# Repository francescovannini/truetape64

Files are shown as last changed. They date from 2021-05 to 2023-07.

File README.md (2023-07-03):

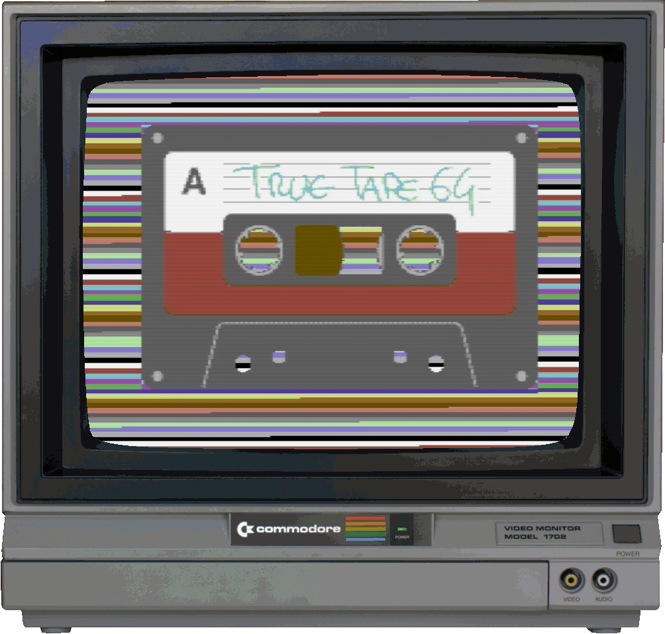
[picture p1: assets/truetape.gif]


# TrueTape64

A cheap, easy to build adapter to interface a [Commodore 1530 (C2N) Datasette ](https://en.wikipedia.org/wiki/Commodore_Datasette) to your PC to dump and preserve your aging Commodore 64 software collection, as accurately as possible.

## What?!

Back in the '80s, many home computers used audio cassette tapes as a medium to to store data. Floppy disks already existed but they often required complex, dedicated hardware; tapes and tape decks on the other hand were cheap, common medium used for music and required simpler or in some cases (like Apple-II) no extra hardware or peripheral. Data was stored encoded as audio and it sounded very similar to the well-known squeaky modem / fax sounds. This storage method had obviously several downsides: long loading/saving times, wasn't "random access" so it required the user to manually advance the tape to the right position to access the desired file; and reliability depended a lot on the quality of the tape. But all these were more than acceptable compromises to keep the prices of these systems down and give everyone a cheap, good-enough way to access or build large software libraries.

As many other future developers born in the '80s, I've started writing BASIC code on a [Commodore 64](https://en.wikipedia.org/wiki/Commodore_64) when I was just a kid. Being still today a huge fan of this platform and having a large collection of tapes, during the past years I've found myself thinking about how to save all this data from the inevitable demise of its aging physical support. 

COVID-19 pandemic gave me some time to finally see if I could figure out how to do that and have some fun while doing it.

### But it has already been done...

Yes, this is certainly not the first project that addresses this issue; in fact I've tried a bunch of existing solutions in the past ([here](http://www.zimmers.net/anonftp/pub/cbm/crossplatform/transfer/datassette/index.html) a comprehensive list) before deciding to design my own device. 

One common approach is based only on clever software: the content of the tape is digitized via a standard audio tape deck (meant for music) connected to the input of a PC sound card. The software then analyzes the audio and extracts the data, performing a variety of corrections and fixes if necessary. This method is quite often the first that many people try, including myself, and usually it is good enough. It requires no weird hardware, however at least in my experience, it requires instead some trial and error; fiddling with volume levels, trying different tape decks and dumping the same tape multiple times to be sure it has been read correctly is the norm. This is because the hardware (tape deck and sound card) is designed for music, not for squeaky, highly-pitched noises. These kind of sounds can be very sensible to things like tape [wow and flutter](https://en.wikipedia.org/wiki/Wow_and_flutter_measurement) and to audio equalization or noise reduction filters; things designed to improve music, not data stored as audio.

Another less common approach involves hooking up the original Datassette to the PC via some sort of adapter. The roughest of these is probably [this one](http://web.archive.org/web/20071130192830/http://www.phs-edv.de/c64s/doc/lpt64.htm) which uses nothing more than a cable and the old-fashioned PC parallel port. This kind of approach requires some skills in building a bit of hardware and it also needs the original Datassette. However, the significant advantage over the software-only approach is that the output dump is closer to what a real Commodore machine would produce or ingest. This is due to the fact that the Datassette is a piece of dedicated hardware, featuring on-board specialized circuitry to clean and digitize the signal so that can be fed directly into the Commodore computer. 

### Design goals

I wanted this project to:

1) Be accurate: given a physical tape, loading it with a real C64 and its Datassette would produce the exact same result than loading the dump of that tape into an emulator when the dump is produced by the same Datassette coupled with this project
2) Be as simple as possible to build and use; bare minimum number of components, designed to be electrically tolerant, safe to use with vintage hardware and requiring minimal tuning; a companion software that does one thing only, but it does it well
3) Be pandemic-proof: all components needed to build the hardware are already in my junk drawer or are easy to obtain from online retailers
3) Be open source: there are similar commercially available devices, not all of them come with schematics or firmware source code. This one does.
4) Be fun and nostalgia fuelled: fiddle with technology designed at the end of the '70s, play with your favourite computer and, in the process, rescue code you wrote when you were 7.

What I've gotten so far:

* a simple hardware device that can be assembled in an hour for less than 10€
* a firmware for the Atmel AVR ATTiny2313 microcontroller which runs the device
* a simple Python command line tool that communicates with the microcontroller and generates a TAP dump of your tape

### Theory of operation

##### Pulse length encoding
The [TAP file format specifications](https://ist.uwaterloo.ca/~schepers/formats/TAP.TXT) gives already some good clues about how the data is stored on the tape and what the emulators such as [VICE](https://vice-emu.sourceforge.io/) expect to find. The Datassette page from [Wikipedia](https://en.wikipedia.org/wiki/Commodore_Datasette#Encoding) is also quite clear:

> To record physical data, the zero-crossing from positive to negative voltage of the analog signal is measured. The resulting time between these positive to negative crossings is then compared to a threshold to determine whether the time since the last crossing is short (0) or long (1).

In practice, the analog signal on the tape is a sine wave which goes from 0 to a minimum negative voltage, then to zero again, then to a maximum positive voltage and finally to zero again; this is fundamentally the entire sine period and it represents a "pulse". The hardware inside the Datassette converts the positive part into a TTL level equivalent to 1 and the negative part to a level equivalent to 0 and sends it over the cable.

This signal is then fed from the Datassette port directly into the C64 [Complex Interface Adapter (CIA)](https://www.c64-wiki.com/wiki/CIA) chip, which would simply run a counter clocked by the system clock to count how many clock cycles the sine period took to complete. In practice, the CIA measures how much time passed between two consecutive falling edges: 
* beginning of the current sine period: negative half-wave on tape, falling edge as seen by the CIA
* end of the current sine period, positive half-wave approaching 0, falling edge as seen by the CIA

If instead of feeding this signal to the CIA we feed it to a microcontroller with a fast enough clock, we could accurately capture the pulse length and then send it somehow to the software running on PC side; tihs is the basic principle behind this project. 

#### Clock speed

But how fast this clock needs to be? The original Commodore LOAD/SAVE routines in the C64 Kernal were designed to be resilient; they used long period pulses producing a relatively low frequency sound which could be safely stored even by low grade tape, but on the other hand loading/saving time were quite long. 

Developers quickly figured out that they could use their own routine to interact directly with the CIA and measure the lenght of each pulse, allowing them to use arbitrary pulse lengths, including very short ones; shorter pulses naturally meant faster loading time. [This article from COMPUTE! magazine](https://www.atarimagazines.com/compute/issue57/turbotape.html) from February 1985 gives an awesome (for a magazine) technical explanation about a popular "tape loader" of the era. Tape loaders were many so many are the different encodings you can find on old tapes. It's therefore obvious that we can't make any assumption on the length of the pulses we could find on the tape; we have to build something that can sample the shortest pulse the CIA can sample. 

We could run the microcontroller at the same clock speed used by the CIA, right? Yes, but how about running it more than TWICE as fast instead? This would ensure we capture data with twice the accuracy as the CIA would do.

##### Sending data over the PC

Once the pulse length is detected we need to send it to our software counterpart running on the PC for it to assemble into the output TAP file. Our microcontroller has a serial port that is fast enough to cope with the bitstream coming from the tape so interfacing that with a ultra common USB adapter is quite convenient. This also provides power to the entire system via the USB port.

##### The Datassette tape motor

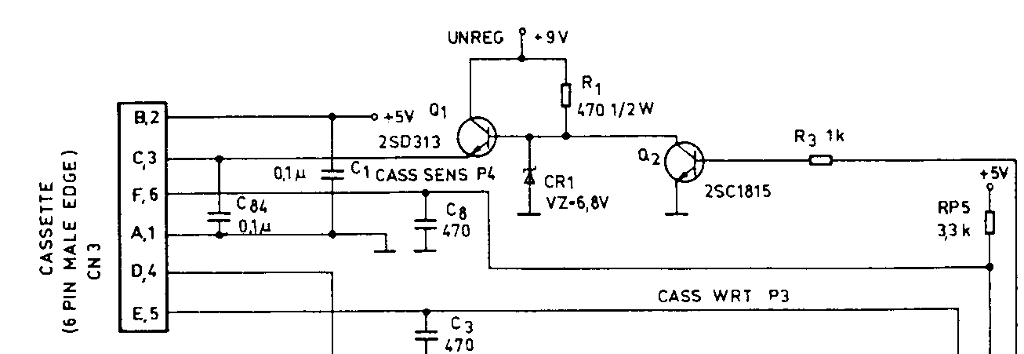
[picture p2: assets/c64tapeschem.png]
c64tapeschem
The Datassette requires two input voltages: a 5V for the TTL logic and a ~6V for the tape motor.  As visible from the original C64 schematics, the C3 pin is fed from the unregulated 9V supplied by the power brick via a transistor and a 6.8V zener diode. This results in a quite stable ~6V output. However the motor voltage isn't critical; each datassette has a slightly different tape speed due to its rudimental mechanics, plus there are different models of Datassette around so the C64 has to be tolerant when measuring pulse length. 

To keep things simple, we opted to include a common DC-DC boost converter to take care of raising the voltage from the USB port from 5V to around 6.1V. Some similar projects use 5V for the motor, running the tape a bit slower and relying on software to compensate for this. I did not try this approach as I was aiming at accuracy but perhaps it would work good enough.

### Schematics and parts

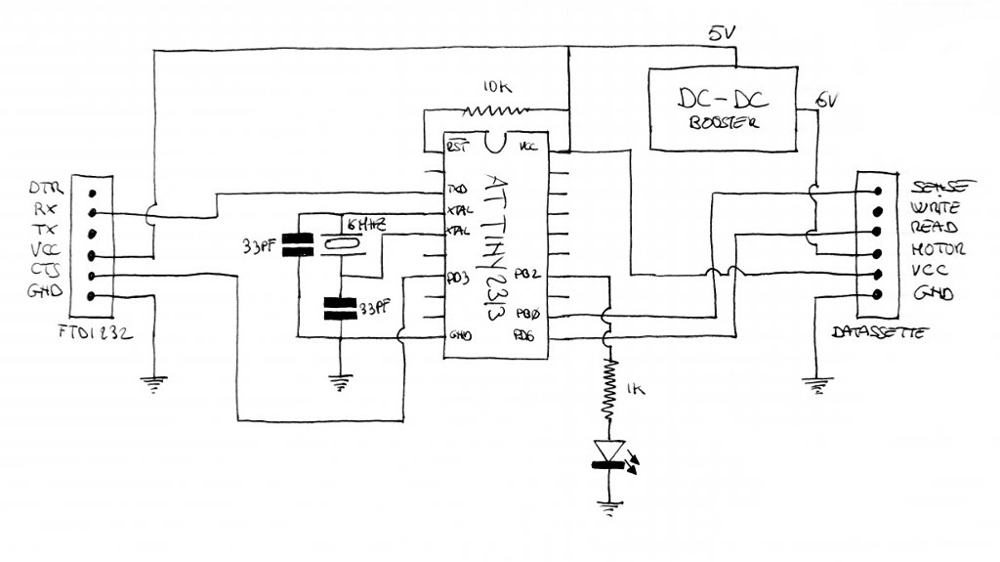
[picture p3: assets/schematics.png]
schematics

Parts:

* [Atmel ATTiny2313-20PU](http://ww1.microchip.com/downloads/en/DeviceDoc/Atmel-2543-AVR-ATtiny2313_Datasheet.pdf)
* 16MHz crystal
* 33pF ceramic capacitors (2x)
* 10KΩ resistor
* 1KΩ resistor
* Red LED
* DC-DC booster module (for example, [this one](https://www.amazon.com/Converter-Voltage-Adjustable-Step-up-Circuit/dp/B07XG323G8/))
* FTDI232 serial to USB adapter (for example, [this one](https://www.amazon.com/HiLetgo-FT232RL-Converter-Adapter-Breakout/dp/B00IJXZQ7C/))
* Datassette edge connector (for example, [this one](https://www.ebay.com/itm/233499875028))
* 5x7 Perf board (for example [this one](https://www.amazon.com/uxcell-Universal-Printed-Circuit-Soldering/dp/B07FK5DWHR))
* 6 pins female header connector

The Datassette READ line is fed directly into PD6/ICP of the uC. This pin is the Input Capture Pin of the 16-bit Timer/Counter1 which can be programmed to generate an interrupt every time a falling edge is detected. The timer runs freely until either an overflow or a falling edge interrupt occurs. In the second case, this allows us to "timestamp" the edge with the value from the counter. 

The clock for the Timer/Counter1 is obtained by dividing by 8 the main clock, which is provided by the 16MHz crystal, giving a 2MHz sample rate. The C64 PAL clock (which is the default in the TAP format) is 985248Hz, so we are more than twice as fast. This should be more than enough to sample tapes for the NTSC model too (which runs at 1.023MHz) although this would probably require a little fix in the Python code. I have no NTSC tapes so I can't test this.

The SENSE line from the Datassette is essentially the output of a microswitch which is closed when one of the buttons on the Datassette is pressed. This is what makes the C64 detect that you "PRESSed PLAY ON TAPE". We capture this event with the micro and forward it to the Python client via the CTS line of the serial port hooked to PD3.

The led is there to signal "buffer overflow" conditions, which should normally never happen. A buffer overflow happens if the data rate from the tape exceeds the data rate of the serial port. We run the serial port at 250Kbps which should be more than enough for most tapes; however, since there is no hardware or software signaling implemented to notify the Python client that an overflow happened, you need to check this led at the end of the dump. If it had turned on, reset the device and try again.

Everything is powered by the USB port, including the DC-DC boost converter for the motor. 

### First (and probably last) prototype

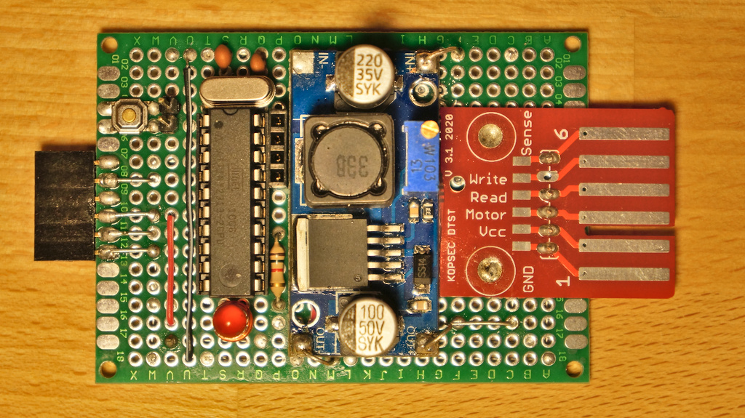
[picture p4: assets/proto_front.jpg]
proto_front

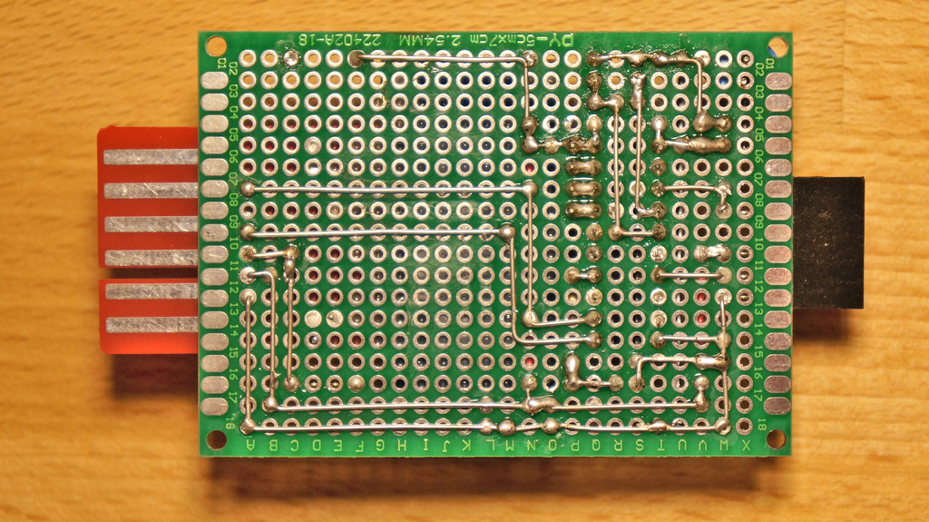
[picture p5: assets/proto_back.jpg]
proto_back

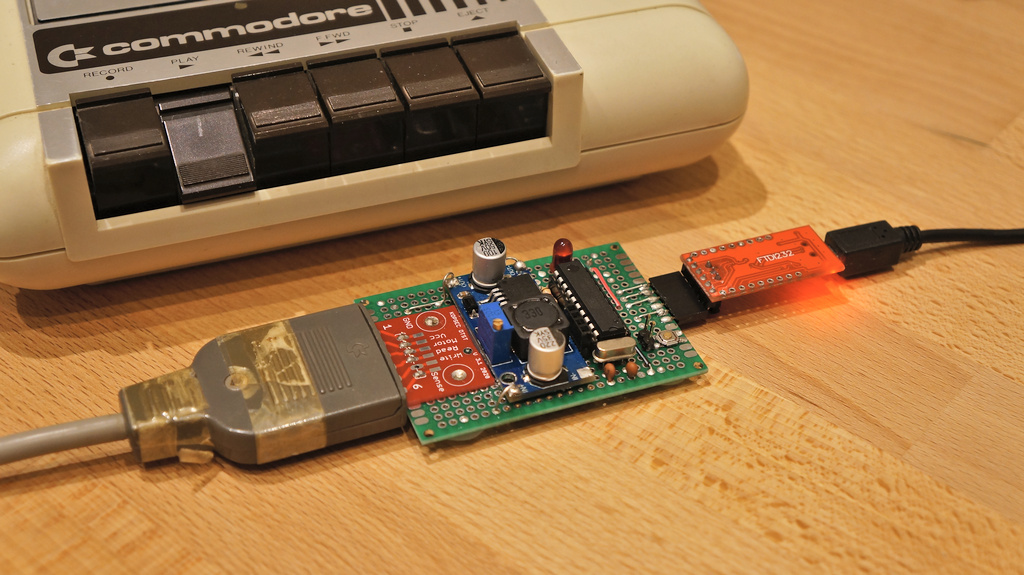
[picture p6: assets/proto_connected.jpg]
proto_connected


Given the simplicity, the whole thing can be built on a perf board or even a breadboard if you don't need a permanent solution. Here the first prototype. The XL6009 booster board is hot-glued on top of the perfboard and connected with rigid wires.

**Adjust the DC-DC boost converter before hooking up a Datassette!** 

Hook up a multimeter between the MOTOR and the GND pins of the Datassette edge connector; using a flat screwdriver, turn the screw on the converter until you read about 6.15V on the multimeter. Now connect the Datassette, put a tape into it and press PLAY. If the voltage drops below 6.1V, adjust the screw again. In any circumstance, be sure the booster never outputs more than 6.5V or you would risk damaging your Datassette motor.

### AVR Firmware

The directory [avr](./avr) in this repo contains the source code of the ATTiny2313 firmware that runs the show on the adapter side. The file `truetape64.hex` is a pre-compiled version of the firmware that you can flash directly onto the AVR using the included Bash script. This script requires avrdude and the usbtiny programmer: check [Lady Ada tutorial](https://learn.adafruit.com/usbtinyisp/avrdude) for further instructions. 

If you flash with your own tool / programmer, remember to also program the fuses:

```
low: 0xFF
high: 0xDF
```

### Python CLI

A simple Python tool is included in the [cli](./cli) directory. The tool opens the serial port of the FTDI adapter and monitors its CTS line; when PLAY is pressed on the Datassette, the tool starts reading the data sent from the microcontroller. After some basic math to account for the differences in frequency between the AVR and the C64 PAL clock, the pulse length is written to the TAP file. The process continues until the CTS line status changes; this can happen either when the tape stops or when there is a buffer overflow; in the latter case, led on the board will be flashing fast until the tape is stopped.

The TAP v2 file format allows for pulse length values for up to 0xFFFFFF (3 bytes). The microcontroller always sends 3 bytes for each pulse, followed by a checksum byte. The checksum is just an extra measure to ensure there is no data corruption during the transfer between the microcontroller and the FTDI adapter, for instance due to a bad solder joint.

See the [README](./cli/) included with the tool for further instructions.

## License
[GPLv3](./LICENSE)

## As seen on Hackaday

This project has been featured on [Hackaday](https://hackaday.com/2021/05/10/truetape64-is-a-pc-interface-for-your-c64-datasette/)

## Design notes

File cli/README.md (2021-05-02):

# TrueTape64 CLI

This tool is part of the TrueTape64 project, aimed at building a simple to build but very reliable interface to dump Commodore 64 tapes into TAP filest suitable to be used with emulators like [Vice](https://vice-emu.sourceforge.io/). Check [here](../) for more infos about the project.

## Installation
    
Be sure to have [pip installed](https://pip.pypa.io/en/stable/installing/), then from the root of this repo, just type
 
    pip3 install .

## Invocation

Simply run the command with no arguments to get help:

    truetape64cli [-d /dev/ttyUSB4] [-y] streetfighter_a.tap
     -d: specify serial device (default is /dev/ttyUSB0) 
     -y: overwrite output file if exists

### Typical output

    $ truetape64cli -d /dev/ttyUSB4 -y streetfighter_a.tap
    PRESS PLAY ON TAPE
    Dumping started
    0 pulses, 0 serial errors, shortest pulse was None
    0 pulses, 0 serial errors, shortest pulse was None
    6 pulses, 0 serial errors, shortest pulse was 26
    13 pulses, 0 serial errors, shortest pulse was 26
    6029 pulses, 0 serial errors, shortest pulse was 20
    16768 pulses, 0 serial errors, shortest pulse was 20

    [...]

    Dumping halted. Dumped 727623 pulses, 0 serial errors, shortest pulse was 2
    Check led status on device

### Practical usage

1) Connect your TrueTape64 adapter to your Commodore Datassette unit
2) Connect your TrueTape64 adapter to one of the USB ports
3) Launch this tool as described above and when prompted...
4) Press PLAY on your Datassette unit
5) Either wait for the tape to reach its end or press STOP when you are done
6) The tool will detect tape activity automatically

If this tool quits before tape reached its end or before you pressed STOP it usually means a hardware error occured during the transfer. This is signaled by a rapidly flashing led on the adapter. In this case press STOP, rewind your tape and start the procedure again. 

The number of serial errors reported by the tool should always be 0. If this number is not zero at the end of the dump, there is a chance that the data has been corrupted or it's missing. If this happens often, replace the FTDI232 adapter with a new one and check the solder joints on your adapter.

## License
[GPLv3](./LICENSE)

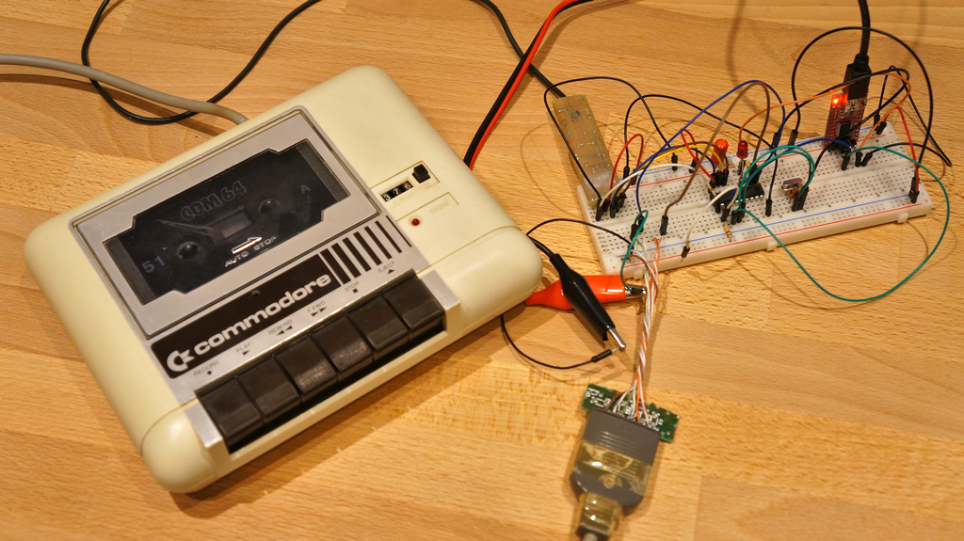
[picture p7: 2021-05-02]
assets/breadboard.jpg

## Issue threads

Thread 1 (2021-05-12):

PCB design

mesmariusz, 2021-05-12:
As I See PCB / gerbers are missing. I'm going to prepare for myself @ KiCad format. If you are interested I could share it for you.

Is this project well tested / works good enough?

francescovannini, 2021-05-12:
I didn't bother producing a proper PCB as this was mostly a small experiment / challenge meant to work just for a few days, to recover all the tapes I have. I tested it with tens of tapes; those which were unreliable after the dump, were unreliable also before, using a real C64; but I could recover data from the dump, so I was definitely happy with the results.
I would certainly be interested in the PCB and schematics if you feel like sharing! Thanks!

mesmariusz, 2021-05-12:
It's great to hear your interface works so much :-) For me this is very nice message, especially because I tried (maybe 25 years ago) the similar solution for LPT port ( https://om.vlip.lv/video/ifxAbwKeGi5f9zE%3D.html ) and it forked for me then (25 years ago). About 3 years ago I try to do it again (many Datasettes, many retro PC's, and many tapeio.exe revisions) but with no result. I dont know why. Everytime load error and notheing more...

https://www.youtube.com/watch?v=Qw3gm-NW9i0&t=20s&ab_channel=MariuszCiszewski
https://www.youtube.com/watch?v=H0MvUC3SV2U&t=80s&ab_channel=MariuszCiszewski
https://www.youtube.com/watch?v=LFOsX8vCoRA&t=4s&ab_channel=MariuszCiszewski

So if your interface works so nice, and with modern PC's (no LPT needed) then for sure and with a great pleasure I will create the circuit drawing and PCB.

Nowadays this is really great if every new hardware is "Arduino compatibile" or build based on Adruino. Even I started to like it ;-). It's easier to program (no programmer is needed, no complicated programm environment, just plug the USB cable, run the Aduino IDE, open .ino file, program and that's all :-) I rally started to like it (previously bare microcontrollers and firmware coded @ Bascom AVR ;-) )

My question: could it be possible for you to prepare the hardware version based on e.g. Arduino Nano (or similar)?
Then I could prepare the hardware ready just to put Arduino module in it, program, and that's all.

If there is any issue to prepare the source @ Arduino language, then of course I can also prepare the documentation (sch, pcb) also for bare microcontroller.

Generally this is really great job, my congratulations :-)

Best regards
Mariusz

francescovannini, 2021-05-13:
Hi Mariusz,

thanks for the feedback! In fact, if you were thinking about an Arduino-based solution, I believe there is already something like this one https://github.com/sweetlilmre/tapuino

mesmariusz, 2021-05-13:
This is possible to connect real Datasette to a PC using Tapuino? Probably not ;-) Tapuino is an emulator / replacement to a real hardware. And I'm searching the nice working solution to connect a real Datasette to a PC. That's quite different topics ;-)

francescovannini, 2021-05-13:
I know, tapuino is kind of the reverse of truetape64, but looking at this board https://github.com/sweetlilmre/tapuino/wiki I see an edge connector; I'm not sure you can directly hook a Datasette there (maybe the motor 6+ voltage isn't provided yet), however I would say that the Tapuino is probably a better starting point for you than my project, since it's already based on Arduino and it more or less has already the hardware that you need...

mesmariusz, 2021-05-13:
Ok, I catch your point right now ;-) I will check the hardware, but the hardware is not an issue in a fact.
The most important is to have checked and well tested Arduino code to implement.
I see your code is also C, so maybe it shouldn't be hard to translate to .ino, but for sure I will find no enough time for that. PCB design is my common daily work right now ;-) It's a several minutes for me. So maybe to make it easier I will prepare the PCB just for bare ATTiny2313 and for Arduino maybe some other day ;-)

francescovannini, 2021-05-13:
Sure, that would be great! For the code, I think it would not make much sense to port it to Arduino as it's extremely simple as it is already and in general bare C performs a little bit better. If you are into circuit design, maybe you can double check if everything is ok, I've surely missed something, I know at least a couple of decoupling capacitors as someone also noticed on Hackaday...

mesmariusz, 2021-05-13:
Generally It make a sense, because e.g. Arduino Nano have build in USB to UART converter, is small and maybe even cheaper (aliexpress) than even single ATTiny microcontroller + FTDI converter + breadboard or universal board. And it's easier and faster to build (just put the arduino to almost bare PCB including edge connector to a Datasette), connect USB cable, upload .ino to Arduino ant thst's all. Easy PCB @ 2 USD per 5 pcs of PCB @ jlpcb, probably it's cheaper and more simple way, even more simple than build it on an universal PCB from a few discrette components ;-)

francescovannini, 2021-05-13:
Precisely! For the hardware what you said it's what Tapuino did ;)

mesmariusz, 2021-05-13:
Tapuino (PCB including edge connector for Datasette variant) is qite big:
https://github.com/sweetlilmre/tapuino/wiki/Tapuino-1.7.jpg

I could make your hardware design:
https://github.com/francescovannini/truetape64/blob/master/assets/proto_connected.jpg?raw=true

much smaller, even smaller than Tapuino ;-)

DC-DC under or above Arduino Nano (similar size), and  just outstanging edge connector for Datasette.
So the final size probably Arduino size and outstanding edge connector :-)

boelle, 2023-09-25:
i just made something in kicad

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

i'm not a programmer, but what would it take to change  the python code so we could also write to tape?

Closed 2022-01-09.

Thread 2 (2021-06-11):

Support record mode

heneault, 2021-06-11:
Thank you for this project. I didn't start it but it is on my todo list!

I would like to know if you consider supporting the record mode ? That would increase the old nostalgic effect by having the ability to push a .tap file from the pc to a real tape being recorded by the 1530. Then, the c64 would be able to read back the tape without compatibility issue since it would have been written by the datassette itself.

francescovannini, 2021-06-25:
Hi! The original purpose of this project was to just dump tapes, not to produce new ones. However, I think with minimal hardware modifications (probably just a couple of extra wires) and a new firmware it would be definitely possible, so why not...

Closed 2022-01-09.

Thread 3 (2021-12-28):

Error sense PIN

Nanths, 2021-12-28:
Hi!

Thank you and congratulations for this project. It seems that the PIN sense was updated in the python code but it wasn't in readme and schematic file. Can you check it? It has to be PD3 but in schematic and readme says PD2. I spent some hours trying to find why it didn't work and what I did wrong, hehe.

Btw, it works great :)

francescovannini, 2022-01-09:
Hey Nanths thanks for spotting this, I've fixed it.
I had changed the ping last minute in the code but forgot to update the docs, sorry for the time you lost on this.
I hope at least it helped dumping some tapes! :)

Closed 2022-01-09.

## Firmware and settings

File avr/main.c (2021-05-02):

#pragma ide diagnostic ignored "hicpp-signed-bitwise"
#pragma ide diagnostic ignored "EndlessLoop"

#include <avr/io.h>
#include <inttypes.h>
#include <avr/interrupt.h>
#include <stdbool.h>
#include <util/delay.h>
#include "main.h"

volatile uint8_t tm_overflows;
volatile pulselen_t pulse_buf[BUF_SIZE];
volatile int8_t pulse_buf_h = -1, pulse_buf_t = -1;
volatile bool pulse_buf_ovf = false;
volatile bool cassette_sense = false;

inline void enqueue_pulse(const volatile uint8_t *tm_overflow, const volatile uint16_t *tm_counter) {

    if ((!cassette_sense) || pulse_buf_ovf) {
        return;
    }

    // Skip too short pulses
    if ((*tm_overflow == 0) && (*tm_counter < MIN_PULSE_LEN)) {
        return;
    }

    if (pulse_buf_h == BUF_SIZE - 1) {
        pulse_buf_ovf = true;
        return;
    }

    if (pulse_buf_h == -1) {
        pulse_buf_h = 0;
    }

    pulse_buf_t++;
    pulse_buf[pulse_buf_t].tm_counter = *tm_counter;
    pulse_buf[pulse_buf_t].tm_overflows = *tm_overflow;
}

inline void send_pulse_data(const volatile pulselen_t *p) {
    uint8_t checksum = 64;

    for (uint8_t i = 0; i < (uint8_t) sizeof(pulselen_t); i++) {
        uint8_t *t = ((uint8_t *) p) + i;
        while (!(UCSRA & (1 << UDRE))) {}
        UDR = *t;
        checksum += *t;
    }

    while (!(UCSRA & (1 << UDRE))) {}
    UDR = checksum;
}

int main(void) {
    bool tmp_sense;

    // Status led
    LED_PORT_DDR |= 1 << LED_PIN;

    // Cassette sense input, Datassette F-6 pin to PB1
    SENSE_IN_PORT_DDR &= ~(1 << SENSE_IN_PIN);
    SENSE_IN_PORT |= 1 << SENSE_IN_PIN; // Pull-up

    // Cassette sense output to serial CTS
    SENSE_OUT_PORT_DDR |= 1 << SENSE_OUT_PIN;
    SET_CASSETTE_SENSE;

    // Capturing falling edges with Timer/Counter 1
    DDRD &= ~(1 << PD6); // Input on PD6
    TIMSK |= (1 << ICIE1) | (1 << TOIE1);     //Set capture interrupt and overflow interrupt
    TCCR1B = (0 << ICNC1) | (0 << ICES1)
             | (0 << CS12) | (1 << CS11) | (0 << CS10);  //Set capture falling edge, /8 prescaler

    // USART init
    UBRRL = UART_UBRR;
    UBRRH = UART_UBRR >> 8;
    UCSRB = (1 << RXEN) | (1 << TXEN) | (0 << U2X); // Enable RX and TX, disable 2X mode
    UCSRC = (0 << USBS) | (1 << UCSZ1) | (1 << UCSZ0); // 8, N, 1

    // Blink when boot done
    LED_PORT |= 1 << LED_PIN;
    _delay_ms(500);
    LED_PORT &= ~(1 << LED_PIN);

    sei();
    for (;;) {

        tmp_sense = !(SENSE_IN_PINS & (1 << SENSE_IN_PIN) >> SENSE_IN_PIN); //FIXME Debounce maybe?
        if (tmp_sense != cassette_sense) {
            cassette_sense = tmp_sense;
            if (cassette_sense) {
                CLR_CASSETTE_SENSE;
            } else {
                SET_CASSETTE_SENSE;
                pulse_buf_ovf = false;
            }
        }

        // Send data in buffer
        if (pulse_buf_h >= 0) {
            send_pulse_data(&pulse_buf[pulse_buf_h]);
            pulse_buf_h++;
            if (pulse_buf_h > pulse_buf_t) {
                pulse_buf_h = -1;
                pulse_buf_t = -1;
            }
        }

        if (pulse_buf_ovf) {
            SET_CASSETTE_SENSE;
            for (uint8_t blink = 0; blink < 5; blink++) {
                LED_PORT |= 1 << LED_PIN;
                _delay_ms(100);
                LED_PORT &= ~(1 << LED_PIN);
                _delay_ms(100);
            }
        } else {
            LED_PORT &= ~(1 << LED_PIN);
        }
    }
}

ISR(TIMER1_CAPT_vect) {
    uint16_t tmp = ICR1;
    TCNT1 = 0;
    enqueue_pulse(&tm_overflows, &tmp);
    tm_overflows = 0;
}

ISR(TIMER1_OVF_vect) {
    const uint16_t max = 0xFFFF;
    if (tm_overflows < 0xFF) {
        tm_overflows++;
    } else {
        enqueue_pulse(&tm_overflows, &max);
        tm_overflows = 0;
    }
}

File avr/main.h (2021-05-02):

#ifndef TRUETAPE64_MAIN_H
#define TRUETAPE64_MAIN_H

#include <inttypes.h>

#define BUF_SIZE            24
#define MIN_PULSE_LEN       9       // Less than this, pulse would appear as 0 in the TAP

#define UART_UBRR           3       // 250kbps at 16Mhz

#define LED_PIN             PB2
#define LED_PORT            PORTB
#define LED_PORT_DDR        DDRB

#define SENSE_IN_PIN        PB0
#define SENSE_IN_PINS       PINB
#define SENSE_IN_PORT       PORTB
#define SENSE_IN_PORT_DDR   DDRB

#define SENSE_OUT_PIN       PD3
#define SENSE_OUT_PORT      PORTD
#define SENSE_OUT_PORT_DDR  DDRD

typedef struct {
    uint16_t tm_counter;
    uint8_t tm_overflows;
} pulselen_t;

#define CLR_CASSETTE_SENSE  SENSE_OUT_PORT &= ~(1 << SENSE_OUT_PIN)
#define SET_CASSETTE_SENSE  SENSE_OUT_PORT |= 1 << SENSE_OUT_PIN

#endif //TRUETAPE64_MAIN_H

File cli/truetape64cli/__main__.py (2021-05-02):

import sys
import getopt
import time
import serial
import os.path
import logging

log = logging.getLogger(__name__)
logging.basicConfig(format='%(message)s', level=logging.INFO)


def verify_checksum(buf):
    checksum = 64
    for bi in range(len(buf) - 1):
        checksum = checksum + buf[bi]

    checksum = checksum % 256

    if buf[3] != checksum:
        return False

    return True


def dump(serial_device, output_file):
    try:
        ser = serial.Serial(serial_device, baudrate=250000, timeout=0)
    except (FileNotFoundError, BrokenPipeError, serial.serialutil.SerialException):
        log.error(f"Cannot open {serial_device}. Be sure it exists and it's connected to the FTDI serial adapter")
        sys.exit(1)

    try:
        tapfile = open(output_file, "w+b")
    except (FileNotFoundError, PermissionError):
        log.error(f"Cannot write to {output_file}.")
        sys.exit(1)

    tap_header = b'\x43\x36\x34\x2D\x54\x41\x50\x45\x2D\x52\x41\x57\x01\x00\x00\x00\x00\x00\x00\x00'
    tapfile.write(tap_header)

    logging.info("PRESS PLAY ON TAPE")
    try:
        while not ser.getCTS():
            time.sleep(0.01)
            continue
    except OSError:
        logging.error("Unrecoverable error while reading from serial device. Aborting")
        sys.exit(1)

    logging.info("Dumping started")

    data_len = 0
    pulses = 0
    shortest_pulse = None
    buffer = bytearray()
    checksum_errors = 0
    last_msg_ts = 0
    dumping = True

    while dumping:

        if time.time() - last_msg_ts > 5:
            last_msg_ts = time.time()
            if pulses > 0:
                logging.info(f"{pulses} pulses, {checksum_errors} serial errors, shortest pulse was {shortest_pulse}")
            else:
                logging.info(f"No pulses detected yet, {checksum_errors} serial errors")

        try:
            b = ser.read()
        except OSError:
            logging.error("Unrecoverable error while reading from serial device. Aborting")
            sys.exit(1)

        if len(b) == 0:
            if not ser.getCTS():
                dumping = False
                continue
            time.sleep(0.1)
            continue

        buffer.append(b[0])
        if len(buffer) == 4:
            if verify_checksum(buffer):
                counter_cycles = buffer[0] + buffer[1] * 0xFF + buffer[2] * 0xFFFF  # 2MHz clock of TC1 via /8 prescaler
                counter_cycles_64 = counter_cycles / 2000000 * 985248  # .98MHz C64 clock conversion
                buffer.clear()
                pulses += 1

                tap_pulse = int(round(counter_cycles_64 / 8 * .985248))

                if shortest_pulse:
                    shortest_pulse = min(shortest_pulse, tap_pulse)
                else:
                    shortest_pulse = tap_pulse

                try:
                    if tap_pulse <= 255:
                        data_len += tapfile.write(tap_pulse.to_bytes(1, byteorder="little", signed=False))
                    else:
                        data_len += tapfile.write(b'\00')
                        data_len += tapfile.write(tap_pulse.to_bytes(3, byteorder="little", signed=False))
                except OSError:
                    logging.error("Unrecoverable error while writing to file. Aborting")
                    sys.exit(1)

            else:
                del buffer[0]
                checksum_errors += 1

    tapfile.seek(16)
    tapfile.write(data_len.to_bytes(4, byteorder="little", signed=False))
    tapfile.close()

    logging.info(
        f"Dumping halted. Dumped {pulses} pulses, {checksum_errors} serial errors, shortest pulse was {shortest_pulse}")
    logging.info("Check led status on device")


def help(exit_error, message=None):
    if message is not None:
        log.warning(message)

    log.warning("truetape64cli [-d /dev/ttyUSB4] [-y] streetfighter_a.tap")
    log.warning(" -d: specify serial device (default is /dev/ttyUSB0)")
    log.warning(" -y: overwrite output file if exists")

    if exit_error:
        sys.exit(1)
    else:
        sys.exit(0)


def run(argv):
    serial_device = "/dev/ttyUSB0"
    output_file = None
    opts = None
    args = None
    overwrite_outfile = False

    try:
        opts, args = getopt.getopt(argv, "hd:y", ["device="])
    except getopt.GetoptError:
        help(True)

    for opt, arg in opts:
        if opt == '-h':
            help(0)
        elif opt in ("-d", "--device"):
            serial_device = arg
        elif opt in ("-o", "--outfile"):
            output_file = arg
        elif opt in "-y":
            overwrite_outfile = True

    if args and args[0] is not None:
        output_file = args[0]
        if os.path.isfile(output_file) and not overwrite_outfile:
            help(1, "Specified output file already exists")
    else:
        help(True)

    dump(serial_device, output_file)


def main():
    try:
        run(sys.argv[1:])
    except KeyboardInterrupt:
        print("Aborted.")
        sys.exit(0)


if __name__ == "__main__":
    main()

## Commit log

2021-05-02 Move led to PB2 while building prototype board Code cleanup
2021-05-02 Fixed sense PIN Added documentation Repo cleanup
    [__main__.py, main.c, main.h]
2022-01-09 Fixed sense pin in documentation
